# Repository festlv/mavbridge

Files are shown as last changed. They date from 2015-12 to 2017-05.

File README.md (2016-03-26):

MAVBridge
------------------

MAVBridge is stand-alone ESP8266 based serial MAVLink <-> wireless bridge. It is compatible
with MAVLink v1.0 specification and 

Compatibility has been tested with:

* Pixhawk hardware (PX4 and ArduPilot flight stacks)
* APMPlanner
* MissionPlanner
* DroidTower
* qGroundcontrol
* MAVProxy

Device has built-in web interface for configuration and status.

At the moment, only UDP transport layer is supported. TCP support is
work-in-progress (functionality is there, but ESP runs out of RAM and crashes
when transmitting a lot of data).

As for performance- UDP has been successfully tested at 921600 baud rate and
almost 70 KiB/s data rate without packet-loss (depends on number of WiFi
networks around device , of course).

Configuration interface
--------------------------------

Index/status page:
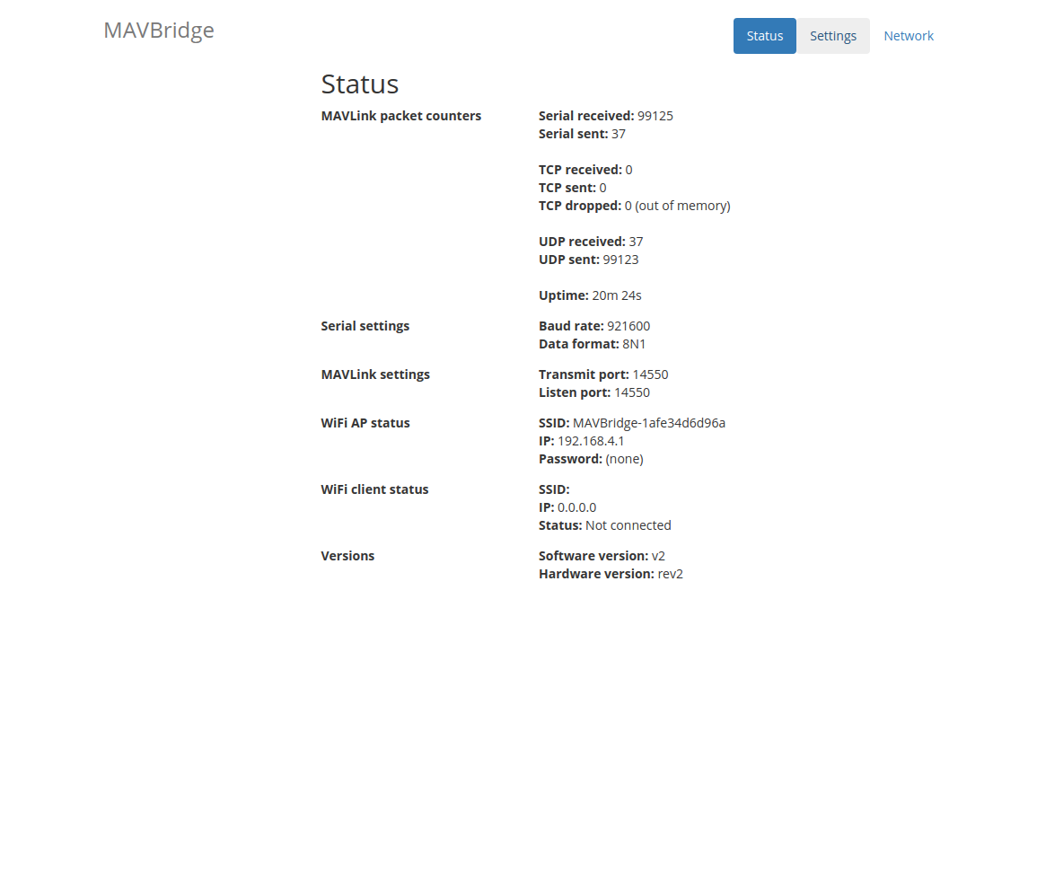
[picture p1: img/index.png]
Screenshot of index page


Settings:
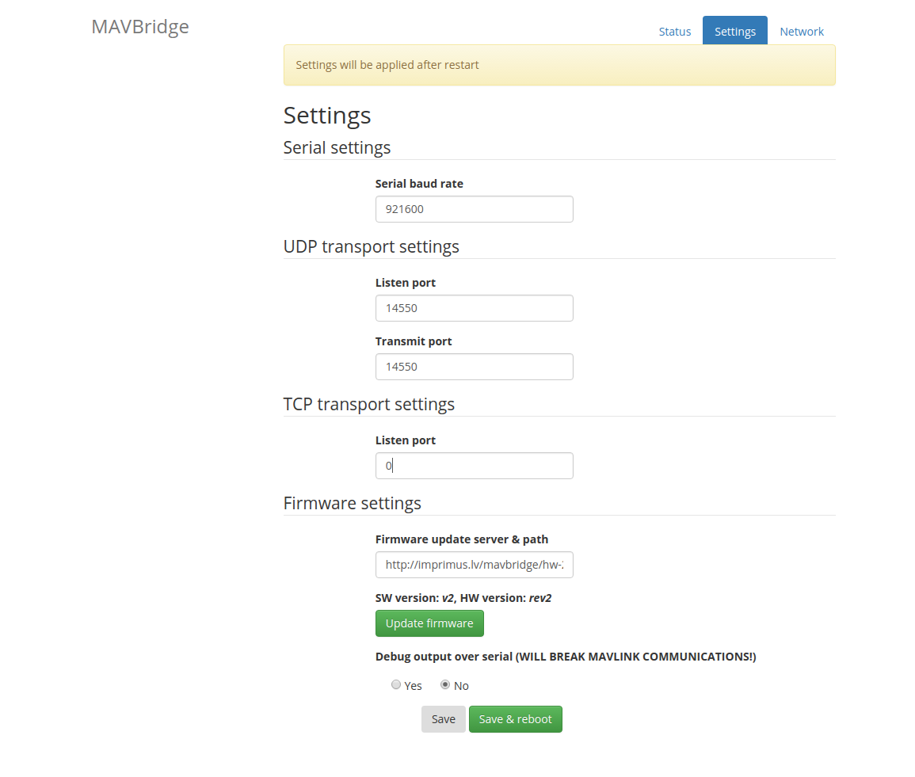
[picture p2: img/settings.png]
Screenshot of settings page


Building firmware
-------------------

Prerequisites for building:
* https://github.com/pfalcon/esp-open-sdk with Espressif IOT SDK 1.5.2
* Sming framework: https://github.com/SmingHub/Sming/releases/tag/2.1.0

Assuming the requirements above are satisfied, building is as simple as:

    cd firmware
    make

Hardware
-----------

Hardware is designed using Kicad and the design is available in hardware
folder.

Testing
--------------

Python scripts that automatically test performance and stability of the
MAVBridge are available in `throughput-test/`. Tests require pymavlink.

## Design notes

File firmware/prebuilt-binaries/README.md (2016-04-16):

Flashing pre-built binaries
----------------------------------

Prebuilt binaries can be flashed to ESP8266 boards (including official
hardware) via serial port.

Required hardware:
* ESP8266-based board,
* USB-TTL adapter (TTL-level, not RS232!)

Required software:
* esptool (https://github.com/themadinventor/esptool)
* OR, on Windows: http://www.electrodragon.com/w/ESP8266_firmware_flasher
  (untested but should work)

For Linux and MacOS, there is a script, `flash.sh` which can be used to
automate the flashing procedure.

Flashing process
------------------------

1. Connect ESP to your serial port (RX to TX, TX to RX, GND to GND, VIN to
   +5V). Do not plug the serial port in USB port of your computer yet.
2. Start the ESP in bootloader mode. For official hardware, the button on board
   needs to be pressed while plugging the serial adapter in USB port. For other
   boards, there might be a similar procedure (see
   https://github.com/themadinventor/esptool#entering-the-bootloader for
   howto).
3. You can now release the button and launch the flashing script with serial
   port device or name as argument:

On success, you should see something like this:

    $ ./flash.sh /dev/ttyUSB0
    Connecting...
    Erasing flash...
    Wrote 2048 bytes at 0x00000000 in 0.2 seconds (82.7 kbit/s)...
    Erasing flash...
    Wrote 309248 bytes at 0x00002000 in 29.9 seconds (82.8 kbit/s)...
    Erasing flash...
    Wrote 524288 bytes at 0x00100000 in 49.1 seconds (85.4 kbit/s)...

    Leaving...

If using GUI to do the flashing you can look up settings in the flashing script
(which .bin file goes to what memory location).

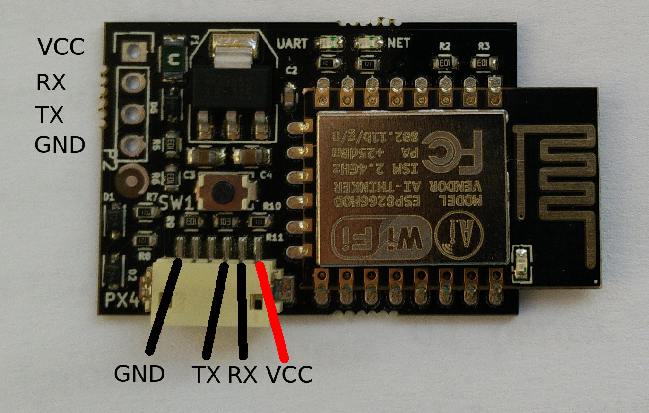
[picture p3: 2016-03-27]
doc/rev2-hw-pinout.jpeg

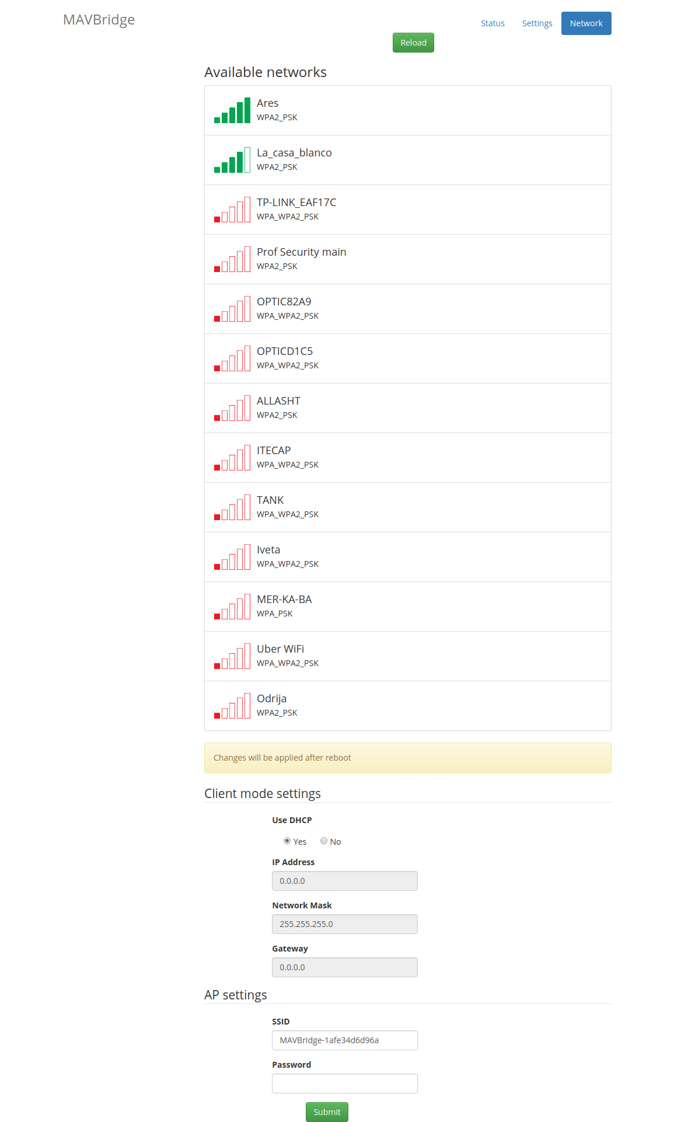
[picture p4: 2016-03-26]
img/network-settings.png

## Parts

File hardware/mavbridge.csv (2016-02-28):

Refs | Characteristics | Description | MFN | MFP | Package ID | S1PL | S1PN | datasheet | footprint | value | Price at 50 units | Price at 100 units
C2 | 50V, 0.1uF X7R |  | Samsung | CMC0603-100N-KX50-S | 603 | https://www.maritex.com.pl/en/cmc0603-100n-kx50-s-i-28284 | CMC0603-100N-KX50-S |  | Capacitors_SMD:C_0603 | 0.1uF | 0,0032 | 0,0032
R10 | 5% 1/10W |  | Yageo | RC0603JR-0710KL | 603 | https://www.maritex.com.pl/en/rmc0603-10k-y-i-43237 | RMC0603-10K-Y |  | Resistors_SMD:R_0603 | 10K | 0,0029 | 0,0029
R2 | 5% 1/10W |  | Yageo | RC0603JR-0710KL | 603 | https://www.maritex.com.pl/en/rmc0603-10k-y-i-43237 | RMC0603-10K-Y |  | Resistors_SMD:R_0603 | 10K | 0,0029 | 0,0029
R3 | 5% 1/10W |  | Yageo | RC0603JR-0710KL | 603 | https://www.maritex.com.pl/en/rmc0603-10k-y-i-43237 | RMC0603-10K-Y |  | Resistors_SMD:R_0603 | 10K | 0,0029 | 0,0029
R5 | 5% 1/10W |  | Yageo | RC0603JR-0710KL | 603 | https://www.maritex.com.pl/en/rmc0603-10k-y-i-43237 | RMC0603-10K-Y |  | Resistors_SMD:R_0603 | 10K | 0,0029 | 0,0029
R6 | 5% 1/10W |  | Yageo | RC0603JR-0710KL | 603 | https://www.maritex.com.pl/en/rmc0603-10k-y-i-43237 | RMC0603-10K-Y |  | Resistors_SMD:R_0603 | 10K | 0,0029 | 0,0029
R9 | 5% 1/10W |  | Yageo | RC0603JR-0710KL | 603 | https://www.maritex.com.pl/en/rmc0603-10k-y-i-43237 | RMC0603-10K-Y |  | Resistors_SMD:R_0603 | 10K | 0,0029 | 0,0029
C3 | 10V X5R 20% |  | Samsung | CL21A106KPFNNNE 10UF 10V 10% X5R | 805 | https://www.maritex.com.pl/en/cmc0805-10u-kx5r-10-s-i-26703 | CMC0805-10U-KX5R-10-S |  | Capacitors_SMD:C_0805 | 10uF | 0,0204 | 0,0204
C4 | 10V X5R 20% |  | Samsung | CL21A106KPFNNNE 10UF 10V 10% X5R | 805 | https://www.maritex.com.pl/en/cmc0805-10u-kx5r-10-s-i-26703 | CMC0805-10U-KX5R-10-S |  | Capacitors_SMD:C_0805 | 10uF | 0,0204 | 0,0204
R1 | 5% 1/10W |  | Samsung | RC1608J121CS | 603 | https://www.maritex.com.pl/en/rmc0603-120r-s-i-30969 | RMC0603-120R-S |  | Resistors_SMD:R_0603 | 120R | 0,0029 | 0,0029
R11 | 5% 1/10W |  | Samsung | RC1608J121CS | 603 | https://www.maritex.com.pl/en/rmc0603-120r-s-i-30969 | RMC0603-120R-S |  | Resistors_SMD:R_0603 | 120R | 0,0029 | 0,0029
R4 | 5% 1/10W |  | Samsung | RC1608J121CS | 603 | https://www.maritex.com.pl/en/rmc0603-120r-s-i-30969 | RMC0603-120R-S |  | Resistors_SMD:R_0603 | 120R | 0,0029 | 0,0029
R7 | 5% 1/10W |  | Samsung | RC1608J121CS | 603 | https://www.maritex.com.pl/en/rmc0603-120r-s-i-30969 | RMC0603-120R-S |  | Resistors_SMD:R_0603 | 120R | 0,0029 | 0,0029
R8 | 5% 1/10W |  | Samsung | RC1608J121CS | 603 | https://www.maritex.com.pl/en/rmc0603-120r-s-i-30969 | RMC0603-120R-S |  | Resistors_SMD:R_0603 | 120R | 0,0029 | 0,0029
U2 | 200mV dropout |  | HTC-Korea | TJ3965S-3.3V-3L | SOT-223-3 | https://www.maritex.com.pl/en/lm3965s-33-i-13481 | LM3965S-3.3 | http://www.mouser.com/ds/2/115/AP7361C-775034.pdf | TO_SOT_Packages_SMD:SOT-223 | LM3965S-3.3 | 0,202 | 0,1905
P3 | DNP | DNP |  |  |  |  |  |  | pin_headers_1.27mm:Pin_Header_1.27mm_2x5 | CONN_02X05
D6 | 0.5A, 30V |  | ON semiconductor | NSR0530HT1G | SOD-323-2 | http://eu.mouser.com/ProductDetail/ON-Semiconductor/NSR0530HT1G | 863-NSR0530HT1G | http://www.mouser.com/ds/2/308/NSR0530H-D-775571.pdf | Diodes_SMD:SOD-323 | D_Schottky | 0,129 | 0,045
U1 |  |  | AI-Thinker | ESP-12E | ESP12E | http://www.aliexpress.com/item/Free-Shipping-10pcs-lot-ESP8266-remote-serial-Port-WIFI-wireless-module-through-walls-Wang-ESP-12/1967135461.html | ESP-12E | https://www.adafruit.com/images/product-files/2471/0A-ESP8266__Datasheet__EN_v4.3.pdf | ESP8266:ESP-12E | ESP-12E | 2,1 | 2,1
F1 | 0.35A hold current, 0.5A trip current, 16V |  | Way-on | LP-NSM035 LEAD FREE | 1206 | https://www.maritex.com.pl/en/rfsn035-i-4600 | RFSN035 | https://www.maritex.com.pl/media/uploads/products/pa/rfsn035.pdf | Resistors_SMD:R_1206 | F_Small | 0,0803 | 0,0594
D4 | Green 0603 LED |  | Hongli | HL-PST-1608H3GC | 603 | https://www.maritex.com.pl/en/light-emitting-diodes-smd-0603-standard-brightness/LED0603-GYW120-H-i-24856-c-11166 | LED0603-GYW120-H | https://www.maritex.com.pl/media/uploads/products/op/PST-1608H3GC.pdf | LEDs:LED-0603 | NET | 0,0367 | 0,0337
P1 |  | DF13 series | Hirose Connector | DF13A-6P-1.25H(20) |  | http://eu.mouser.com/ProductDetail/Hirose-Connector/DF13A-6P-125H20/ | 798-DF13A6P125H20 | http://www.mouser.com/ds/2/185/en_DF13_20130411-268487.pdf | DF13:DF13-6 | PX4 | 0,434 | 0,38
SW1 |  | NO pushbutton | Innocent | INT-1440F20A |  | https://www.maritex.com.pl/en/tactd44h20b160-i-22931 | TACTD44H20B160 |  | tact_switch:TACT_SW_TACTD44H20B160 | SW_PUSH | 0,1331 | 0,1193
W1 |  |  |  |  |  |  |  |  | Measurement_Points:Measurement_Point_Round-SMD-Pad_Small | TEST_1P
W2 |  |  |  |  |  |  |  |  | Measurement_Points:Measurement_Point_Round-SMD-Pad_Small | TEST_1P
W3 |  |  |  |  |  |  |  |  | Measurement_Points:Measurement_Point_Round-SMD-Pad_Small | TEST_1P
W4 |  |  |  |  |  |  |  |  | Measurement_Points:Measurement_Point_Round-SMD-Pad_Small | TEST_1P
W5 |  |  |  |  |  |  |  |  | Measurement_Points:Measurement_Point_Round-SMD-Pad_Small | TEST_1P
W6 |  |  |  |  |  |  |  |  | Measurement_Points:Measurement_Point_Round-SMD-Pad_Small | TEST_1P
W7 |  |  |  |  |  |  |  |  | Measurement_Points:Measurement_Point_Round-SMD-Pad_Small | TEST_1P
W8 |  |  |  |  |  |  |  |  | Measurement_Points:Measurement_Point_Round-SMD-Pad_Small | TEST_1P
W9 |  |  |  |  |  |  |  |  | Measurement_Points:Measurement_Point_Round-SMD-Pad_Small | TEST_1P
D3 | Red 0603 LED |  | Hongli | HL-PST-1608S9AC 50-70MCD | 603 | https://www.maritex.com.pl/en/light-emitting-diodes-smd-0603-standard-brightness/LED0603-RW120-i-28429-c-11166 | LED0603-RW120 | https://www.maritex.com.pl/media/uploads/products/op/1608S9AC.pdf | LEDs:LED-0603 | UART | 0,0241 | 0,023
P2 | 2.54mm pitch 1x4 pin |  | Ulo | ULO-PH409-1*4SF11 |  | https://www.maritex.com.pl/en/pls04su-i-35905 | PLS04SU | https://www.maritex.com.pl/media/uploads/PRODUKTY_PDF/con/PLSXXSU.pdf | Pin_Headers:Pin_Header_Straight_1x04 | UART | 0,0138 | 0,0126
D1 | 3.4V zener |  | ON Semiconductor | MM3Z3V3ST1G | SOD-323 | http://eu.mouser.com/ProductDetail/ON-Semiconductor/MM3Z3V3ST1G/?qs=HVbQlW5zcXUr40rey9MAng%3D%3D | 863-MM3Z3V3ST1G | http://www.mouser.com/ds/2/308/MM3Z2V4ST1-D-95078.pdf | Diodes_SMD:SOD-323 | 3.4V zener | 0,04 | 0,04
D2 | 3.4V zener |  | ON Semiconductor | MM3Z3V3ST1G | SOD-323 | http://eu.mouser.com/ProductDetail/ON-Semiconductor/MM3Z3V3ST1G/?qs=HVbQlW5zcXUr40rey9MAng%3D%3D | 863-MM3Z3V3ST1G | http://www.mouser.com/ds/2/308/MM3Z2V4ST1-D-95078.pdf | Diodes_SMD:SOD-323 | 3.4V zener | 0,04 | 0,04

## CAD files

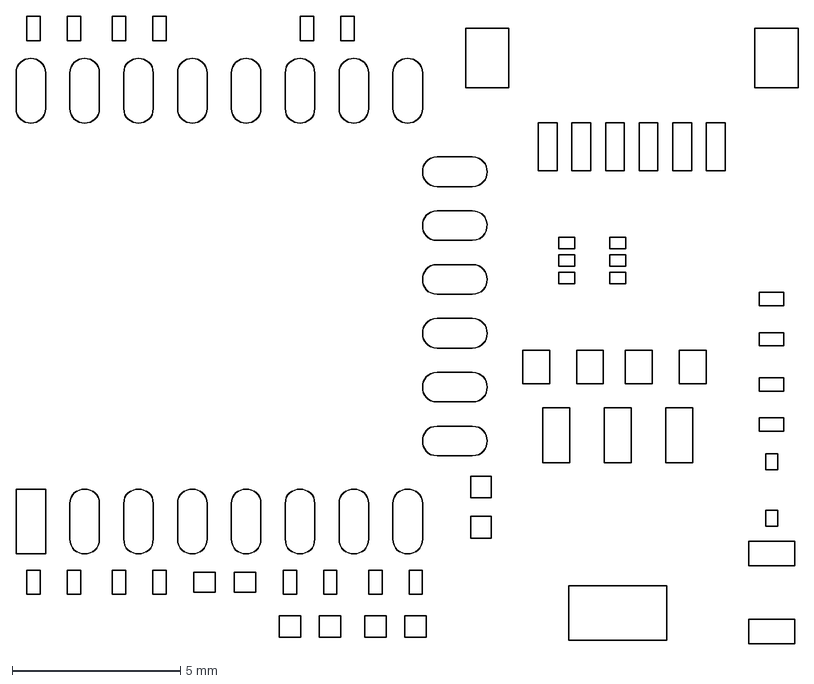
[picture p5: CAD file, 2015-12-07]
hardware/out/#solderpaste-top.dxf
23.2 x 18.6 mm

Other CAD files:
hardware/out/solderpaste-top.dxf

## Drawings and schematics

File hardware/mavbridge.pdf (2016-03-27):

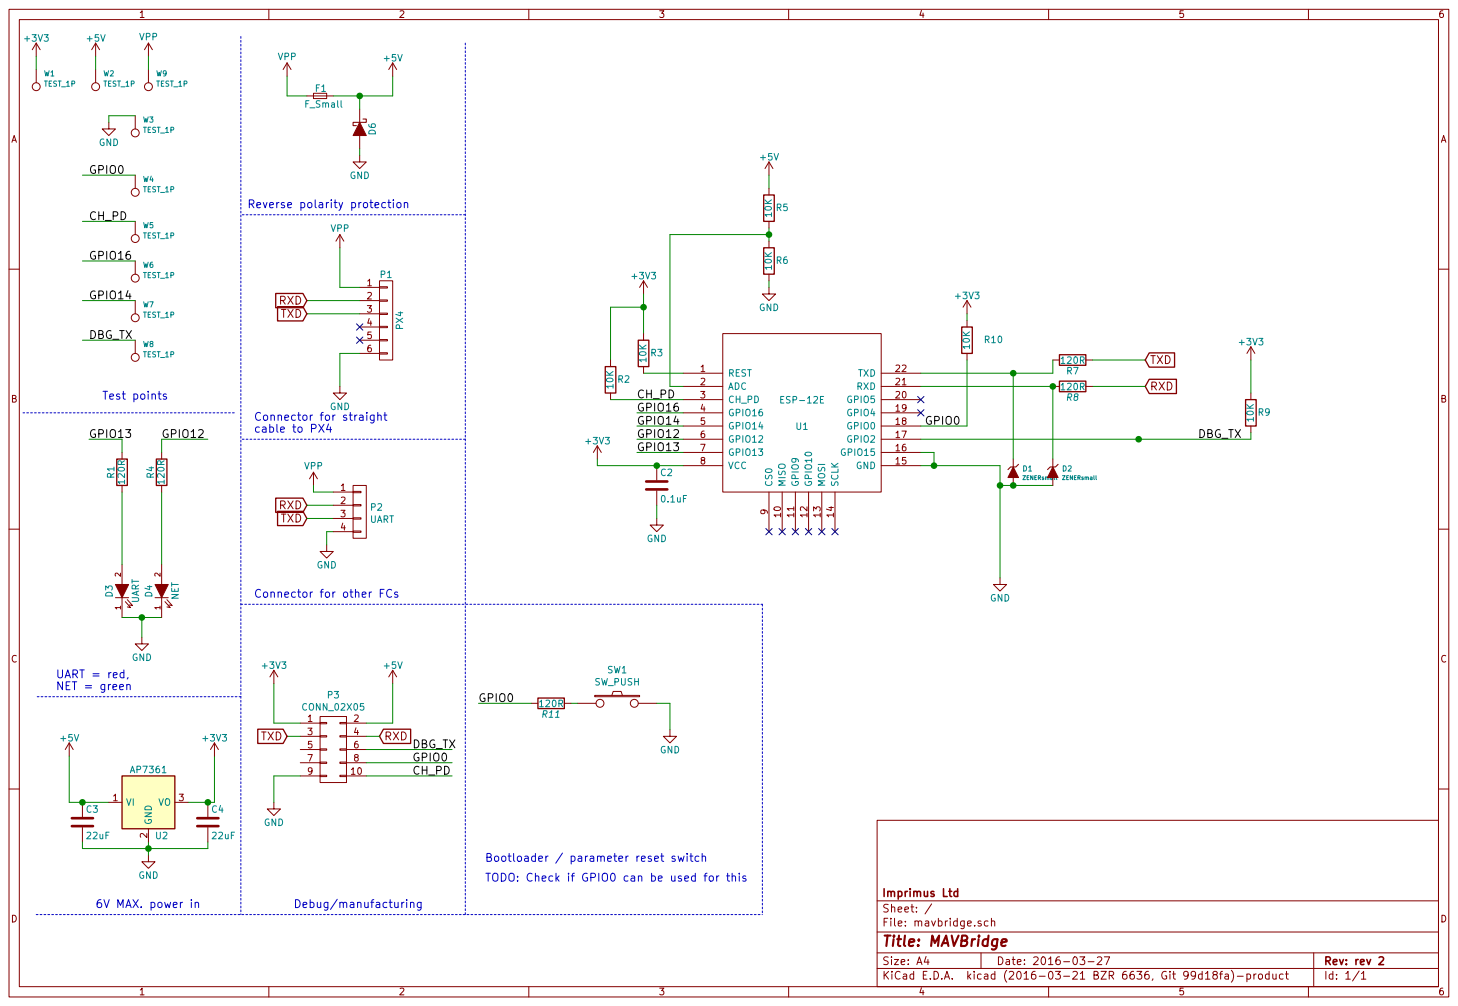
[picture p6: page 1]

9 MISO 10 GPIO5 20 GPIO9 11 RXD 21 GPIO10 12 TXD 22 MOSI 13 SCLK 14 GND 15 GPIO15 16 GPIO2 17 GPIO0 18 GPIO4 19 U1 ESP-12E GND

Connector for straight cable to PX4 Connector for other FCs

TODO: Check if GPIO0 can be used for this R11

Imprimus Ltd
File: mavbridge.sch Sheet: /
Id: 1/1 Title: MAVBridge

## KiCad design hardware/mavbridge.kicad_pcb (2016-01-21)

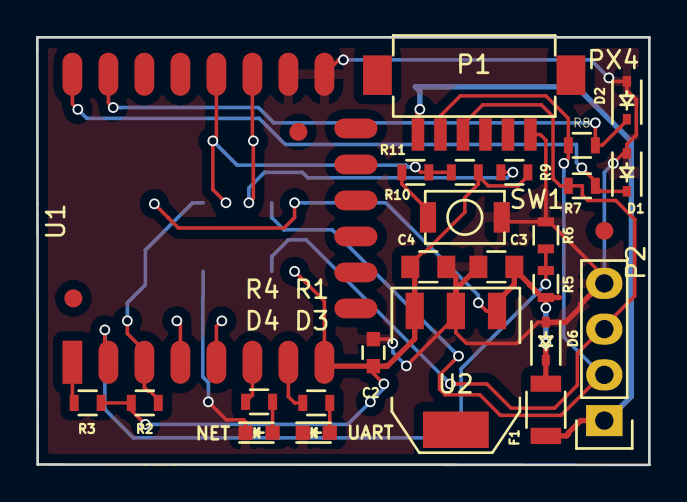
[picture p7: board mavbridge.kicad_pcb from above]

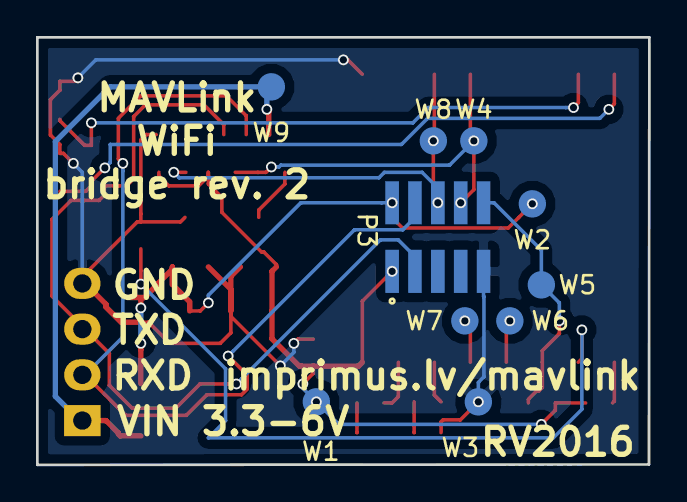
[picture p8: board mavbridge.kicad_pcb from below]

Board: 2 copper layers, 34.0 x 23.8 mm, 35 parts (10 on the bottom side), 20 nets.

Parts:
C2: 0.1uF; C_0603
C3, C4: 22uF; C_0805
D1, D2: ZENERsmall; SOD-323
D3: UART; LED-0603
D4: NET; LED-0603
D6: D_Schottky; SOD-323
F1: F_Small; R_1206
P1: PX4; DF13-6
P2: UART; Pin_Header_Straight_1x04
P3: CONN_02X05; Pin_Header_1.27mm_2x5
R1, R4, R7, R8, R11: 120R; R_0603
R2, R3, R5, R6, R9, R10: 10K; R_0603
SW1: SW_PUSH; TACT_SW_TACTD44H20B160
U1: ESP-12E
U2: AP7361; SOT-223
W1, W2, W3, W4, W5, W6, W7, W8, W9: TEST_1P; Measurement_Point_Round-SMD-Pad_Small

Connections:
+3V3: C2.1, C4.1, P3.1, R2.2, R3.2, R9.2, R10.2, U1.8, U2.3, W1.1
+5V: C3.1, D6.1, F1.2, P3.2, R5.2, U2.1, W2.1
/CH_PD: P3.10, R2.1, U1.3, W5.1
/DBG_TX: P3.6, R9.1, U1.17, W8.1
/GPIO0: P3.8, R10.1, R11.2, U1.18, W4.1
/GPIO12: R4.2, U1.6
/GPIO13: R1.2, U1.7
/GPIO14: U1.5, W7.1
/GPIO16: U1.4, W6.1
GND: C2.2, C3.2, C4.2, D1.2, D2.2, D3.1, D4.1, D6.2, P1.6, P2.4, P3.9, R6.1, SW1.2, U1.15, U1.16, U2.2, W3.1
unnamed: D1.1, R7.2, U1.22
unnamed: D2.1, R8.2, U1.21
unnamed: D3.2, R1.1
unnamed: D4.2, R4.1
unnamed: R3.1, U1.1
unnamed: R5.1, R6.2, U1.2
unnamed: R11.1, SW1.1
RXD: P1.2, P2.2, P3.4, R8.1
TXD: P1.3, P2.3, P3.3, R7.1
VPP: F1.1, P1.1, P2.1, W9.1

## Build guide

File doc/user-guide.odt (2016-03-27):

MAVBridge quickstart guide

1. Connect MAVBridge to your autopilot and power it on.
2. Use your computer to connect to wireless network “MAVBridge-xxxx”.
3. Open http://192.168.4.1 in your browser and configure serial baud rate to match autopilot settings and restart MAVBridge.
4. Open your ground control station software. If it does not connect automatically, set up a new UDP connection to “<your-computers-IP>:14550”. Typically this will be 192.168.4.2:14550

See http://imprimus.lv/mavbridge for more information.

MAVBridge quickstart guide

1. Connect MAVBridge to your autopilot and power it on.
2. Use your computer to connect to wireless network “MAVBridge-xxxx”.
3. Open http://192.168.4.1 in your browser and configure serial baud rate to match autopilot settings and restart MAVBridge.
4. Open your ground control station software. If it does not connect automatically, set up a new UDP connection to “<your-computers-IP>:14550”. Typically this will be 192.168.4.2:14550

See http://imprimus.lv/mavbridge for more information.

MAVBridge quickstart guide

1. Connect MAVBridge to your autopilot and power it on.
2. Use your computer to connect to wireless network “MAVBridge-xxxx”.
3. Open http://192.168.4.1 in your browser and configure serial baud rate to match autopilot settings and restart MAVBridge.
4. Open your ground control station software. If it does not connect automatically, set up a new UDP connection to “<your-computers-IP>:14550”. Typically this will be 192.168.4.2:14550

See http://imprimus.lv/mavbridge for more information.

MAVBridge quickstart guide

1. Connect MAVBridge to your autopilot and power it on.
2. Use your computer to connect to wireless network “MAVBridge-xxxx”.
3. Open http://192.168.4.1 in your browser and configure serial baud rate to match autopilot settings and restart MAVBridge.
4. Open your ground control station software. If it does not connect automatically, set up a new UDP connection to “<your-computers-IP>:14550”. Typically this will be 192.168.4.2:14550

See http://imprimus.lv/mavbridge for more information.

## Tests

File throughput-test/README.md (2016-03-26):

Performance / stability testing scripts
---------------------------------------------

This set of scripts allows to test the performance and reliability of the
MAVBridge. `mavspoof.py` sends out MAVLink packets over serial port,
`mavrecv.py` receives them on network.

Usage:

    mavspoof.py --baud 115200 /dev/ttyUSB0

Receiving UDP data:

    mavrecv.py 192.168.4.2:14550

Where `192.168.4.2` is IP address of PC and 14550 is default port for MAVLink
over UDP. It might be neccessary to initiate a connection to `192.168.4.255:14550` first
because pymavlink doesn't listen for broadcasts.

Receiving TCP stream:

    mavrecv.py tcp:192.168.4.1:5760

Where `192.168.4.1` is IP address of MAVBridge (server) and 5760 is default port
for MAVLink over TCP.

Automated testing
----------------------
    
test.py contains test case for automated testing. It assumes that nmcli is
available and tries to connect to WiFi SSID "MAVBridge-"

    $ python2 -m unittest discover
    Setting up udp broadcasts
    Setting up test processes
    ...
    Sent 36368 packets, 1599912 bytes
    Received 36368 packets, 1599912 bytes, 67537.33 bytes/sec
    Packet loss: 0.0%
    .
    ----------------------------------------------------------------------
    Ran 1 test in 26.803s

    OK

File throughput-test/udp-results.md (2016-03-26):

Baud rate: 115200, UDP

    9.7KiB/s (maximum for this baud rate):

    Sent 1365 packets, 59955 bytes
    Received 1365 packets, 59955 bytes, 9761.56 bytes/sec
    Packet loss: 0.0%

Baud rate: 921600, UDP

    16 KiB/s:

    Sent 2275 packets, 99925 bytes
    Received 2275 packets, 99925 bytes, 16098.65 bytes/sec
    Packet loss: 0.0%

    45 KiB/s:

    Sent 6820 packets, 299905 bytes
    Received 6820 packets, 299905 bytes, 45751.94 bytes/sec
    Packet loss: 0.0%
    
    67 KiB/s:

    Sent 36368 packets, 1599912 bytes
    Received 36368 packets, 1599912 bytes, 67537.33 bytes/sec
    Packet loss: 0.0%

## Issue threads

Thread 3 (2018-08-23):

ESP-32 Support?

salocinx, 2018-08-23:
Hi.

Thanks for the great project. I tried to flash the MavBridge project to a ESP8266 and it works really fine. However, I need to run it on a ESP32. I tried it too and flashing the ESP32 does not output any errors, but it also does not open an AP like on the ESP8266.

Any chance that you will support ESP32 in the near future? If not, some tips how to achieve would be highly appreciated : )

Best regards,
Nicolas

festlv, 2018-08-28:
This project currently does not support ESP32. Currently I have no plans in adding the support, as I don't use mavbridge too often.

It looks like the framework/library I used when developing mavbridge does not support ESP32 either: https://github.com/SmingHub/Sming/issues/1333

salocinx, 2018-09-06:
Thanks for your answer. I will try to substitute the Sming library with something adequate.

faxik, 2019-07-17:
Just in case, maybe any progress was done in that direction?

Closed 2018-08-28.

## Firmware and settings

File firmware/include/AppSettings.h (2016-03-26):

#ifndef INCLUDE_APPSETTINGS_H_
#define INCLUDE_APPSETTINGS_H_

#include <user_config.h>
#include <SmingCore/SmingCore.h>


#define APP_SETTINGS_FILE ".settings.conf" // leading point for security reasons :)

#define DEFAULT_TCP_PORT 0
#define DEFAULT_MAVLINK_PORT 14550
#define DEFAULT_OTA_LINK FW_UPDATE_LINK
#define DEFAULT_MAVLINK_BAUDRATE 57600

//empty means autogenerated MAVBridge-<mac address>
#define DEFAULT_AP_SSID ""

//empty- open network
#define DEFAULT_AP_PASSWORD ""

#define RESTORE_PARAMETERS_PIN 0

class ApplicationSettingsStorage
{

public:
	String ssid;
	String password;

    String ap_password;
    String ap_ssid;
    
	bool dhcp = true;
    bool debug_output = false;

	IPAddress ip;
	IPAddress netmask;
	IPAddress gateway;

    /** Custom options
     */
    int baud_rate;

    int mav_port_in;
    int mav_port_out;

    int tcp_mav_port_in;

    String ota_link;

    void restore();

	void load();
	
	void save();

	bool exist();
};

extern ApplicationSettingsStorage AppSettings;

void app_settings_tick_10hz();

#endif /* INCLUDE_APPSETTINGS_H_ */

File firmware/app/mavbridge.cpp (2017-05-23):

#include <user_config.h>
#include <SmingCore/SmingCore.h>

#include "AppSettings.h"

#include "mavbridge.h"

#define MAX_CLIENTS 5
#define MAX_INTERFACES 2

//@TODO: this is wrong and depends on netmask
#define BROADCAST_ADDRESS(ip) (IPAddress(ip[0],ip[1],ip[2],255))

void check_serial_buffer();
void check_network_buffer();
Timer uart_recv_timer, net_recv_timer;


//Sming has this removed in recent versions
#ifndef RX_BUFF_SIZE
#define RX_BUFF_SIZE 256
#endif

// Will be called when WiFi hardware and software initialization was finished
// And system initialization was completed
void ready()
{
	// If AP is enabled:
	debugf("AP. ip: %s mac: %s", WifiAccessPoint.getIP().toString().c_str(), WifiAccessPoint.getMAC().c_str());

    uart_recv_timer.initializeMs(1, check_serial_buffer).start();
    net_recv_timer.initializeMs(1, check_network_buffer).start();

    MavlinkServer::get_instance().initialize(AppSettings.mav_port_in, PROTO_UDP);
    MavlinkServer::get_instance().initialize(AppSettings.tcp_mav_port_in, PROTO_TCP);
}

void check_network_buffer() {
    static mavlink_packet_t in_packet;

    if (MavlinkServer::get_instance().pop_received_packet(&in_packet)) {
        digitalWrite(NET_LED_PIN, 1);
        for (int i = 0; i < in_packet.length; i++) {
            //really inefficient but should do the trick
            Serial.write(in_packet.data[i]);
        }

        MavlinkServer::get_instance().ct_uart_out++;
        digitalWrite(NET_LED_PIN, 0);    
    }

    return;
}

void check_serial_buffer() {
    static mavlink_message_t* msg;
    static uint8_t in_buffer[RX_BUFF_SIZE];
    int read_len = Serial.readMemoryBlock((char*)in_buffer, RX_BUFF_SIZE);


    if (read_len > 0) {
        digitalWrite(UART_LED_PIN, 1);
    }

    for (int idx=0; idx < read_len; idx++) {
        if (MavlinkServer::decoder.parse_char(in_buffer[idx]) == MSG_DECODED) {
            msg = MavlinkServer::decoder.get_message();
            MavlinkServer::get_instance().queue_packet(*msg);
            MavlinkServer::get_instance().ct_uart_in++;
        }
    }
    digitalWrite(UART_LED_PIN, 0);
}

void mavbridge_init() 
{
    pinMode(UART_LED_PIN, OUTPUT);
    pinMode(NET_LED_PIN, OUTPUT);

    digitalWrite(UART_LED_PIN, 1);
    digitalWrite(NET_LED_PIN, 1);

    delay(200);
    digitalWrite(UART_LED_PIN, 0);
    digitalWrite(NET_LED_PIN, 0);

	// Set system ready callback method
	System.onReady(ready);
}



Timer MavlinkServer::interface_update_timer;
Timer MavlinkServer::transmit_window_timer;

Vector<IPAddress> MavlinkServer::udp_clients;
Vector<IPAddress> MavlinkServer::interfaces;
Vector<TcpClient*> MavlinkServer::tcp_clients;
Vector<mavlink_packet_t> MavlinkServer::incoming_message_queue;


bool MavlinkServer::pop_received_packet(mavlink_packet_t* packet) {
    if (incoming_message_queue.size() > 0) {
        *packet = incoming_message_queue[0];
        incoming_message_queue.removeElementAt(0);
        return true;
    }
    return false;
}

bool MavlinkServer::client_exists(IPAddress ip, mavlink_proto_type_t proto) {

    bool found = false;
    if (proto == PROTO_UDP) {
        for (int i=0; i < udp_clients.size(); i++) {
            if (udp_clients[i] == ip) {
                found = true;
                break;
            }
        }
    }
    return found;
}

bool MavlinkServer::interface_exists(IPAddress ip) {

    bool found = false;
    for (int i=0; i < interfaces.size(); i++) {
        if (interfaces[i] == ip) {
            found = true;
            break;
        }
    }
    return found;
}

void MavlinkServer::interface_update_interrupt() {
    //update interface_ips with IP addresses of currently active interfaces
    if (WifiAccessPoint.isEnabled()) {
        if (!interface_exists(BROADCAST_ADDRESS(WifiAccessPoint.getIP()))) {
            interfaces.add(BROADCAST_ADDRESS(WifiAccessPoint.getIP()));
        }
    }

    //update station IP address if connected
    if (WifiStation.isEnabled() && WifiStation.isConnected()) {
        if (!interface_exists(BROADCAST_ADDRESS(WifiStation.getIP()))) {
            interfaces.add(BROADCAST_ADDRESS(WifiStation.getIP()));
        }
    }
}

bool MavlinkServer::tcp_client_receive(TcpClient &client, char* data, int size) {
    //reject too large packets
    if (size > MAVLINK_MAX_PACKET_LEN) {
        return false;
    }

    debugf("TCP < %d bytes\n", size);
    static mavlink_packet_t packet; 
    memcpy(&packet.data, data, size); 
    packet.length = size;
    incoming_message_queue.add(packet);
    ct_tcp_in++;
    return true;
}

void MavlinkServer::tcp_client_connected(TcpClient* client) {
    //adds to the list of connections
    
    for (int i=0; i < tcp_clients.size(); i++) {
        if (tcp_clients[i] == client)
            return;
    }
    //not found
    tcp_clients.add(client);  
    debugf("Adding TCP client\n");
}

void MavlinkServer::tcp_client_complete(TcpClient& client, bool successful) {
    //find the client in list of connections and remove it
    for (int i=0; i < tcp_clients.size(); i++) {
        if (tcp_clients[i] == &client) {
            //client found, remove it
            tcp_clients.removeElementAt(i);
            debugf("Removing TCP client: %d\n");
            break;
        }
    }
}

void MavlinkServer::udp_receive_callback(UdpConnection &conn, char* data, int size,
                IPAddress remoteIP, uint16_t remotePort) {
    if (!client_exists(remoteIP, PROTO_UDP)) {
        udp_clients.add(remoteIP);
    }
    //reject too large packets
    if (size > MAVLINK_MAX_PACKET_LEN) {
        return;
    }

    debugf("UDP < %d bytes\n", size);

    static mavlink_packet_t packet; 
    memcpy(&packet.data, data, size); 
    packet.length = size;
    incoming_message_queue.add(packet);
    ct_udp_in++;
}

UdpConnection* MavlinkServer::udp_conn = NULL;
TcpServer* MavlinkServer::tcp_server = NULL;

void MavlinkServer::initialize(uint16_t port, mavlink_proto_type_t protocol)
{

    bool start_timer = false;

    if (protocol == PROTO_UDP && port != 0) {
        if (udp_conn != NULL) {
            delete udp_conn;
        }
        udp_conn = new UdpConnection(MavlinkServer::udp_receive_callback); 
        udp_conn->listen(port);
        debugf("MavlinkServer listening to UDP at %d\n", port); 
        start_timer = true;

    } else if (protocol == PROTO_TCP && port != 0) {
        if (tcp_server != NULL) {
            delete tcp_server;
        }
        tcp_server = new TcpServer(MavlinkServer::tcp_client_connected, 
                MavlinkServer::tcp_client_receive,
                MavlinkServer::tcp_client_complete);
        tcp_server->listen(port);

        debugf("MavlinkServer listening to TCP at %d\n", port); 
        start_timer = true;
    }

    if (start_timer) {
        interface_update_timer.initializeMs(1000, MavlinkServer::interface_update_interrupt).start();
        transmit_window_timer.initializeMs(20, MavlinkServer::transmit_buffer).start();
    }
}
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

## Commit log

2015-12-07 Adds rev 1 hardware.
    [#solderpaste-top.dxf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]
2015-12-09 Fixes parameter saving/restoring.
    Also AP name now contains MAC address.
    [AppSettings.h, web_config.cpp]
2015-12-11 Prints debug output to UART1 (on GPIO2).
2015-12-14 Removes debug serial, custom UART1 driver not stable.
2015-12-14 Adds silkscreen pinout for HW layout
    [mavbridge.csv, mavbridge.kicad_pcb]
2016-01-02 Adds component fields
    [mavbridge.sch]
2016-01-16 Changes to firmware:
    * Blinks UART/NET LEDs;
    * Increases UART receive timer frequency;
    * Loads app settings before testing for existence;
2016-01-17 Adds feature which resets parameters when GPIO is held low for 3 seconds.
    [AppSettings.h, app_settings.cpp, application.cpp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]
2016-01-21 Ordered rev2 hardware.
    [mavbridge-B.Cu.gbl, mavbridge-B.Mask.gbs, mavbridge-B.SilkS.gbo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]
2016-02-28 Updates BOM from Maritex
    [mavbridge.csv]
2016-02-28 Adds pricing information.
    [mavbridge.csv]
2016-03-27 Adds schematics in PDF format.
    [mavbridge.sch]
